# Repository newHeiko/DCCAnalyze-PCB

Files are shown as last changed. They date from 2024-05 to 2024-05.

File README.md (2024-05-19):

# DCCAnalyze hardware

This repo contains the PCB files for a stand-alone DCC analyzer.

## DCCAnalyze firmware

The firmware can be found at [newHeiko/DCCInspector-EX](https://github.com/newHeiko/DCCInspector-EX) which is an extension of [DCC-EX/DCCInspector-EX](https://github.com/DCC-EX/DCCInspector-EX) by the following points (some tbd).

- [x] Add support for Arduino Nano Every
- [ ] Add support for keys
- [ ] Add support for LCD

## Building DCCAnalyze hardware

The PCB was created with kicad 8.0, the production files with the Fabrication Toolkit.

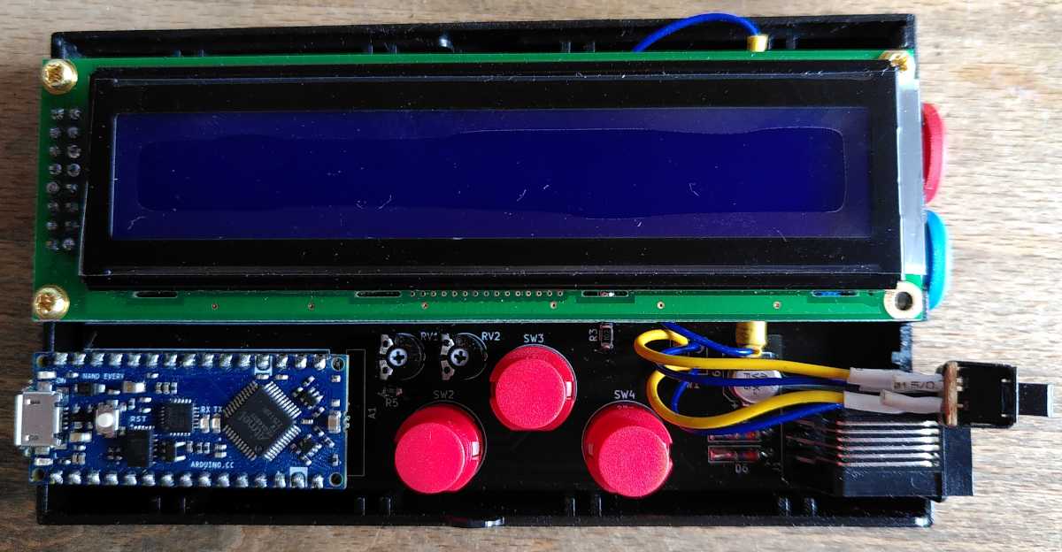
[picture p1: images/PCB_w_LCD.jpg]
View of my first prototype


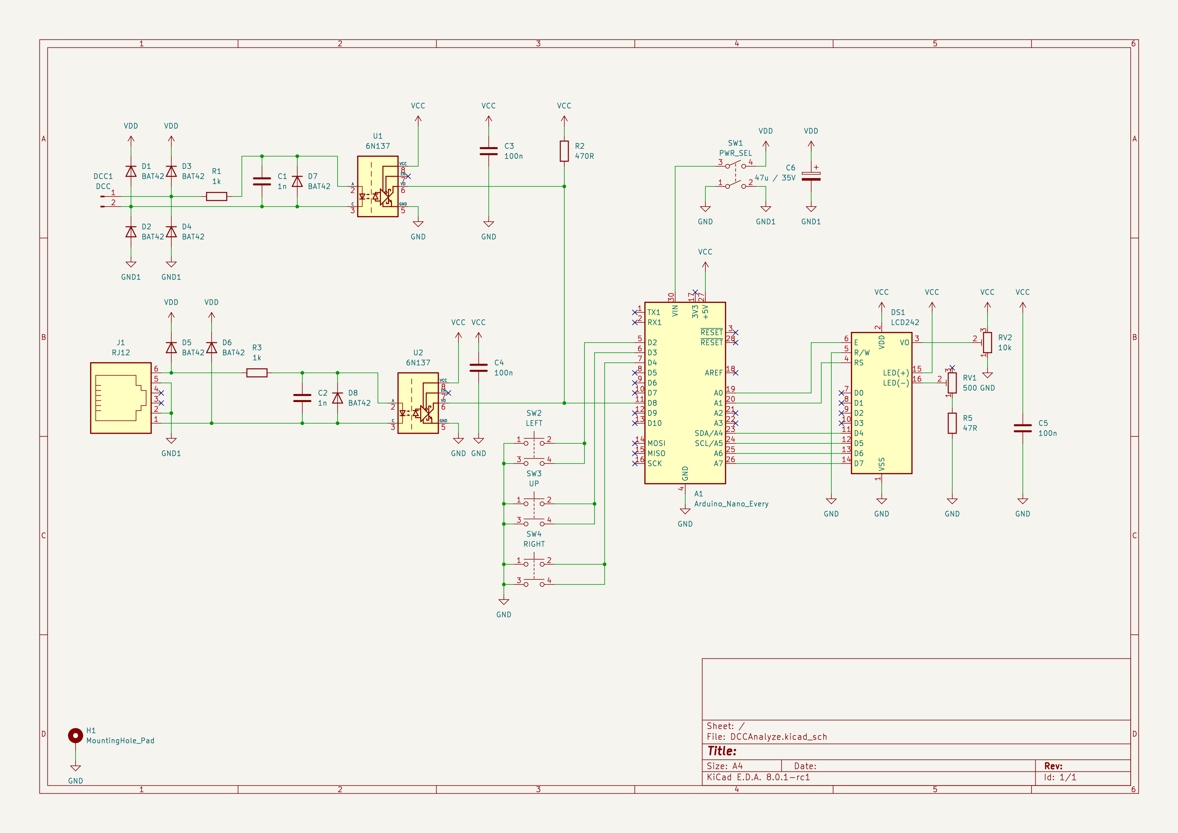
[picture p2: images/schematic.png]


Most of the parts are from my box of spare and leftover parts, which is why I mixed different size SMD parts, some also rather unusual.

This is the full partlist:
| Parts | Value | Notes / Source |
| ----- | ----- | --- |
| A1 | Arduino Nano Every | [Reichelt](https://www.reichelt.de/arduino-nano-every-atmega4809-ohne-header-ard-nano-eve-p261300.html?&nbc=1) |
| C1, C2 | 1nF  | 0805  |
| C3, C4, C5 | 100nF | 1206 |
| C6 | 47µF  | Dia 6.3mm, min 25V |
| D1, D2, D3, D4, D5, D6, D7, D8 | BAT42 | MiniMELF |
| J1 | RJ12-connector | [Reichelt](https://www.reichelt.de/modular-einbaubuchse-6-6-schwarz-mebp-6-6s-p11370.html?&nbc=1) |
| R1, R3 | 1kOhm | 1206 |
| R2 | 470Ohm | 1206 |
| R5 | 47Ohm | 0805 |
| RV1 | 500 Ohm | Piher PT-6 [Reichelt](https://www.reichelt.de/einstellpotentiometer-liegend-500-ohm-6-mm-pt-6-l-500-p14989.html?&nbc=1) |
| RV2 | 10kOhm | Piher PT-6 [Reichelt](https://www.reichelt.de/einstellpotentiometer-liegend-10-kohm-6-mm-pt-6-l-10k-p14982.html?&nbc=1) |
| SW2, SW3, SW4 | Digitast DT6 | [Reichelt](https://www.reichelt.de/eingabetaster-schaltspannung-100v-rund-sw-dt-6-sw-p7241.html?&nbc=1) |
| U1, U2 | 6N137 | DIP8 |
| LCD | 24x2 | [Reichelt](https://www.reichelt.de/lcd-modul-2x24-h-5-6mm-bl-ws-m-bel--lcd-242a-bl-p53951.html?&nbc=1) |
| SW1 | DPST or DPDT | [Reichelt](https://www.reichelt.de/schiebeschalter-miniatur-loetanschluss-2x-um-sw-t-217-p19976.html?&nbc=1) |
| DCC | 2x SKS SEB 2610 F4,8 | 2x [Reichelt](https://www.reichelt.de/einbaubuchse-4-mm-faston-gelb-gesichert-seb-2610f-ge-p106132.html?&nbc=1) |
| PinHeader for A1 | 2x 1x16 | 2x [Reichelt](https://www.reichelt.de/stiftleisten-2-54-mm-1x16-gerade-mpe-087-1-016-p119887.html?&nbc=1) |
| Socket for A1 | 2x 1x16 | 2x [Reichelt](https://www.reichelt.de/buchsenleisten-2-54-mm-1x16-gerade-mpe-094-1-016-p119919.html?&nbc=1) |
| PinHeader for LCD | 2x8 | [Reichelt](https://www.reichelt.de/stiftleisten-2-54-mm-2x08-gerade-mpe-087-2-016-p119897.html?&nbc=1) |
| Socket for LCD | 2x8 | [Reichelt](https://www.reichelt.de/buchsenleiste-2x8-pol-vergoldet-2-54-bkl-10120808-p235674.html?&nbc=1) |
| 3x LCD stand-offs | 3x M2.5 x 12mm | |
| LCD screws | 6x M2.5 x 6mm | |
| PCB screw | 1x Dia 2.9mm x 6.5mm | |
| Enclosure | | 2x [Reichelt](https://www.reichelt.de/kunststoff-halbschale-123-x-70-x-14-5-mm-sd-10-gr-halb-p149274.html?&nbc=1) |

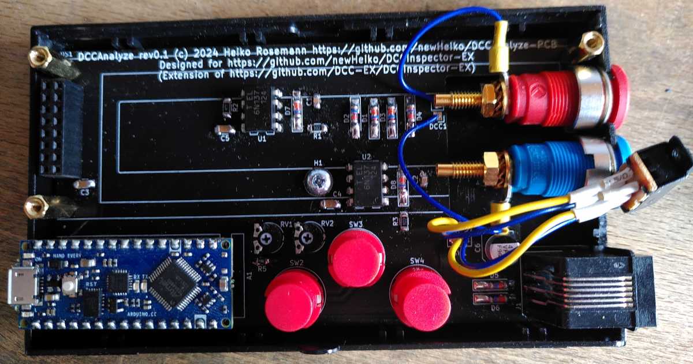
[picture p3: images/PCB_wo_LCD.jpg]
PCB inside the lower half of the housing, with the LCD removed


The device can decode the DCC signal either from the loconet(r) plug and its Railsync signal or from the two 4mm sockets. The sockets included in the BOM above are shorter than the ones I used for my prototype - they should fit in the recess of the PCB.

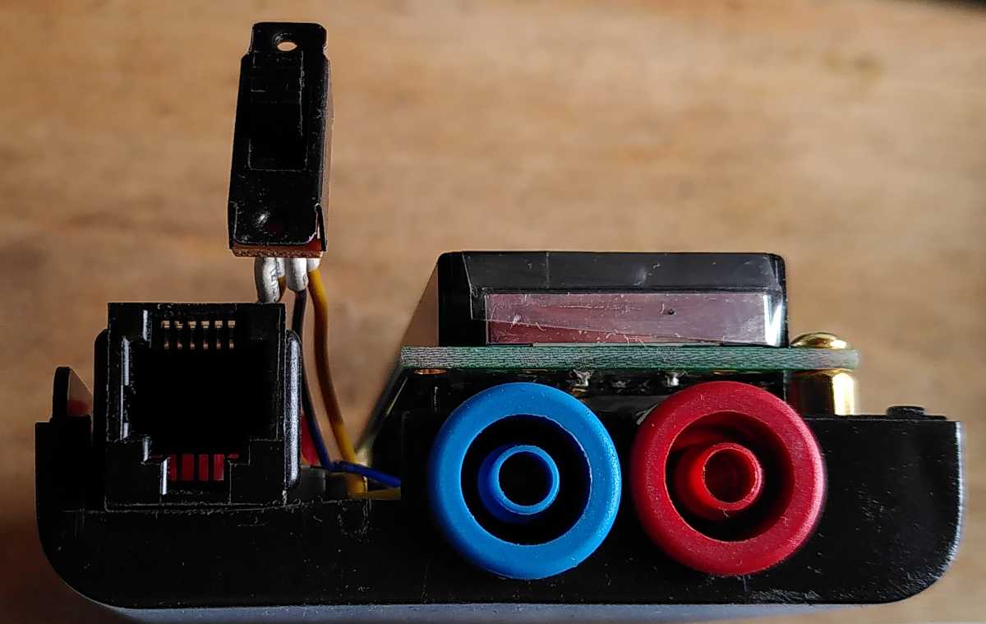
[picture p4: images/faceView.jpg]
Side view of the device


Power can come from the USB connection (then the DCC inputs both are optically isolated from everything else) or from the DCC / Railsync signal (then the USB connection is not required and the device can be used stand-alone). Power draw from DCC / Railsync is about 25mA-30mA at 15V.

The switch SW1 switches the device power from USB to DCC/Railsync. It should fit vertically between the RJ12 socket and the LCD / 4mm plugs.

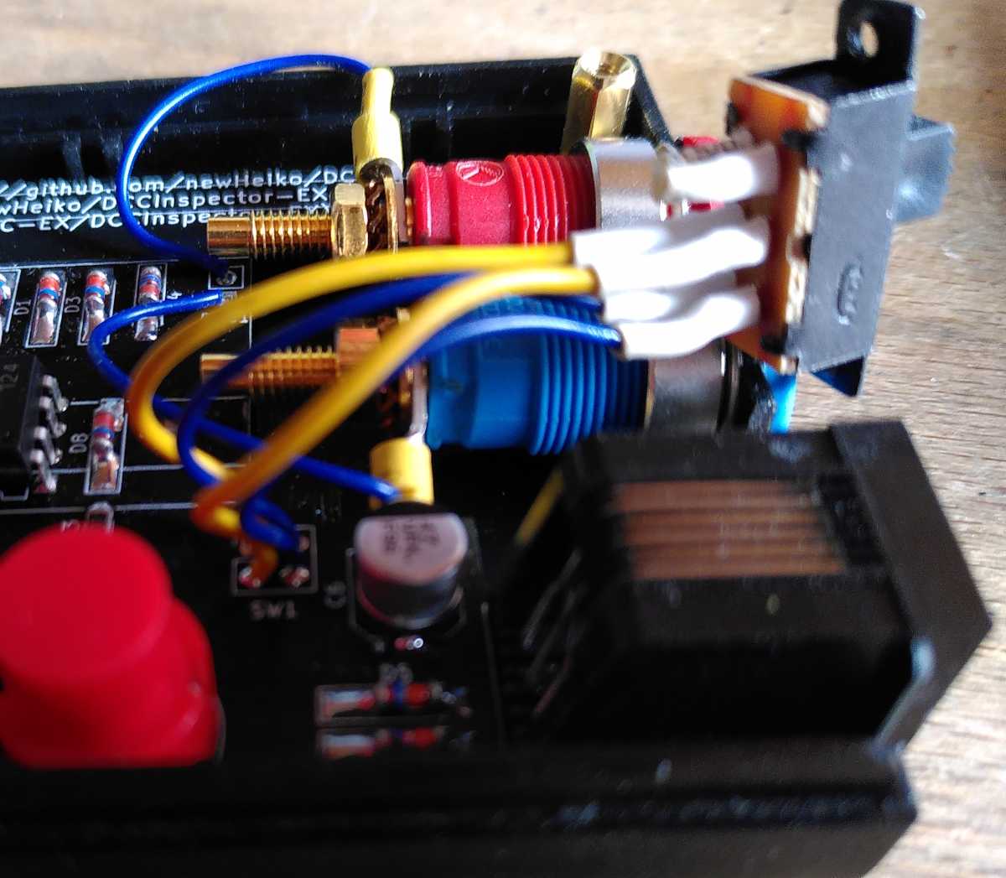
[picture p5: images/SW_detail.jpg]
Detail view of power switch connection


Note that for the switch, the polarity matters. In the image above, the lower yellow wire needs to connect to the lower blue wire and the upper yellow wire to the upper blue wire.

You may substitute a classic Arduino Nano for the Arduino Nano Every, but the integrated linear voltage regulator of the classic Arduino Nano will probably get very hot. Beware of DCC / Railsync input voltages above ~12V or so in that case.

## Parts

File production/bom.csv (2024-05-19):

Designator | Footprint | Quantity | Value | LCSC Part #
A1 | Arduino_Nano | 1 | Arduino_Nano_Every
C1, C2 | 0805 | 2 | 1n
C3, C4, C5 | 1206 | 3 | 100n
C6 | CP_Elec_6.3x5.8 | 1 | 47u / 35V
D1, D2, D3, D4, D5, D6, D7, D8 | D_MiniMELF_Handsoldering | 8 | BAT42
DCC1 | PinHeader_1x02_P2.54mm_Vertical | 1 | DCC
DS1 | LCD242 | 1 | LCD242
J1 | RJ12_Amphenol_54601-x06_Horizontal | 1 | RJ12
R1, R3 | 1206 | 2 | 1k
R2 | 1206 | 1 | 470R
R5 | 0805 | 1 | 47R
RV1 | Potentiometer_Piher_PT-6-V_Vertical | 1 | 500
RV2 | Potentiometer_Piher_PT-6-V_Vertical | 1 | 10k
SW1 | PinHeader_2x02_P2.54mm_Vertical | 1 | PWR_SEL
SW2 | Push_E-Switch_KS01Q01 | 1 | LEFT
SW3 | Push_E-Switch_KS01Q01 | 1 | UP
SW4 | Push_E-Switch_KS01Q01 | 1 | RIGHT
U1, U2 | DIP-8_W7.62mm | 2 | 6N137

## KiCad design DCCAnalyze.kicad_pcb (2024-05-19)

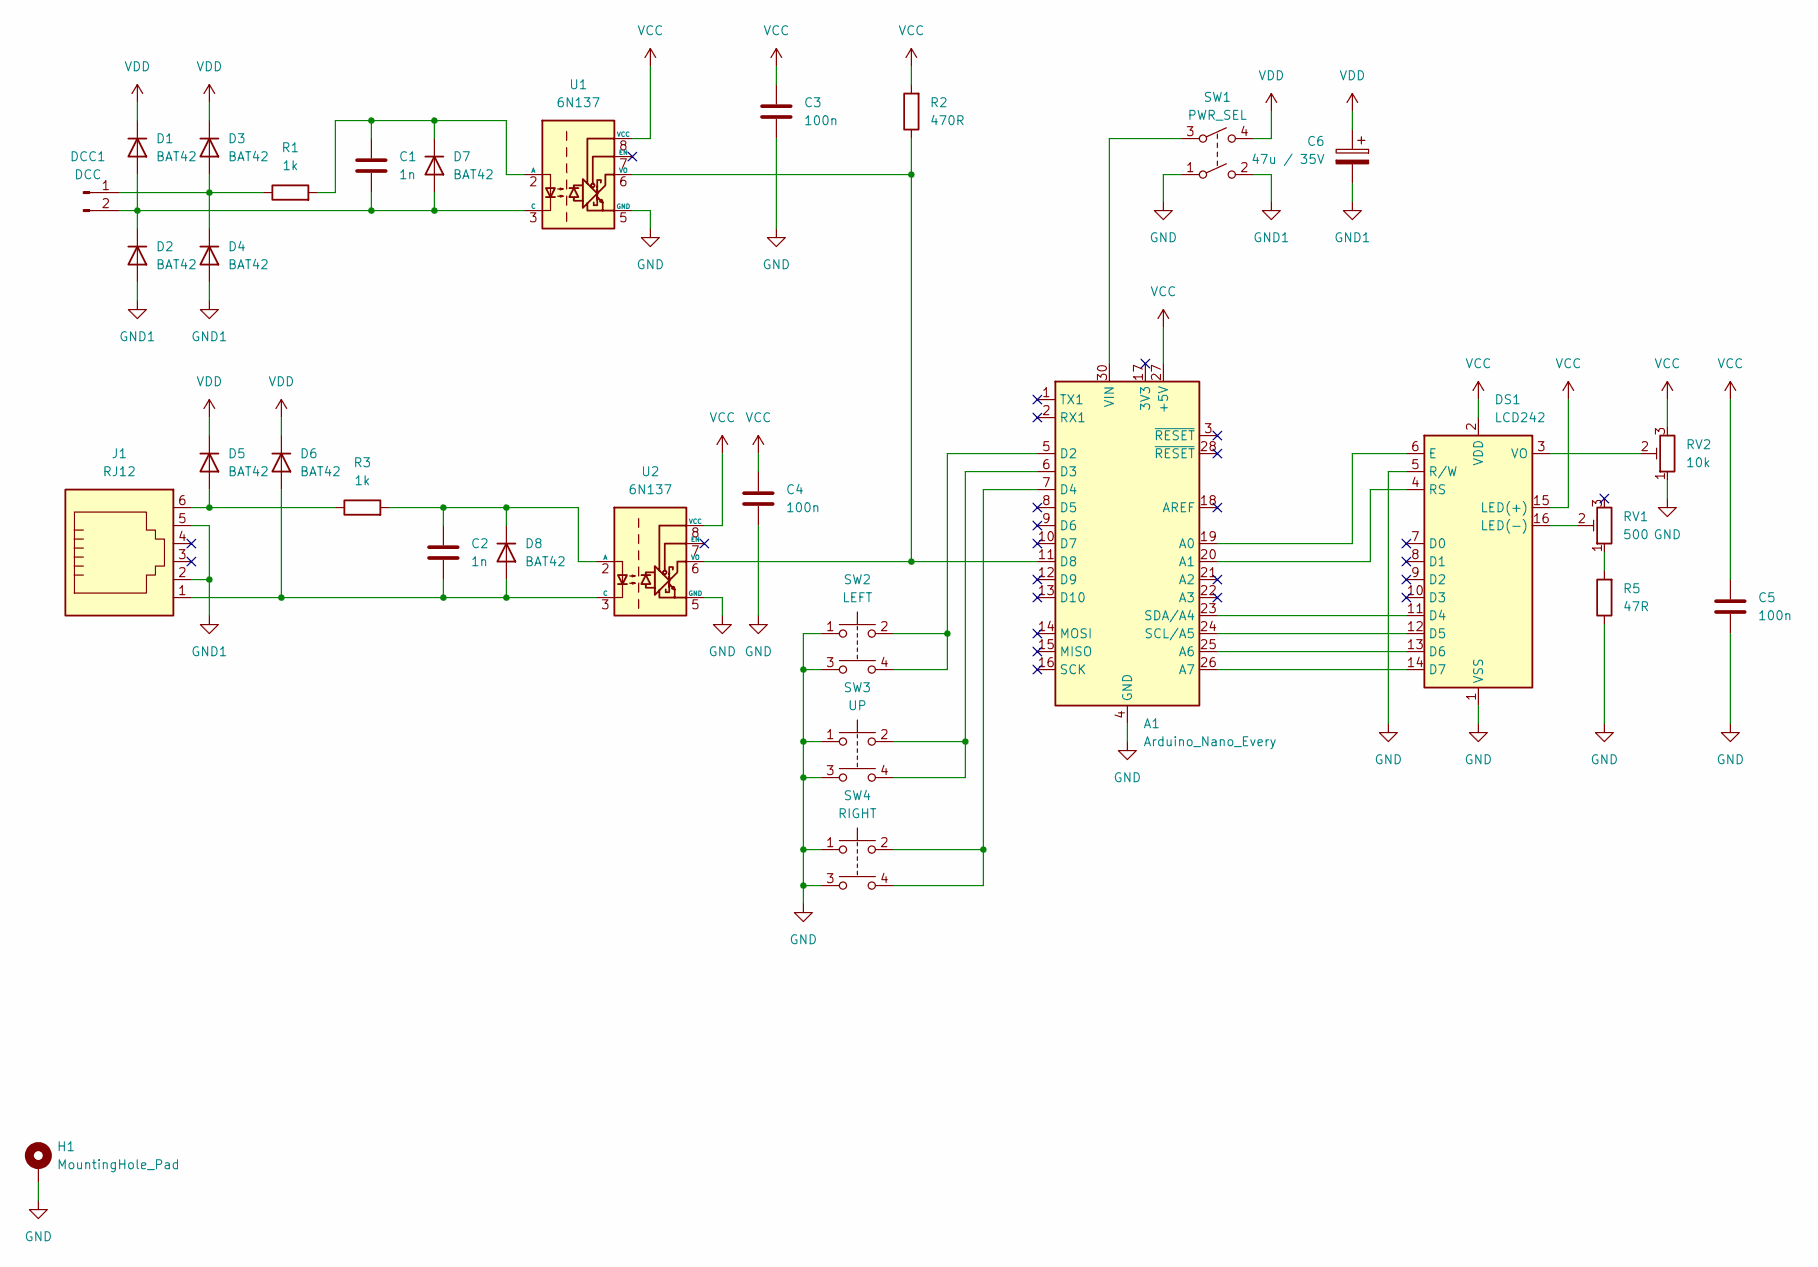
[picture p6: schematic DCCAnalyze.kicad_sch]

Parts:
A1: Arduino_Nano_Every; Arduino_Nano
C1, C2: 1n; C_0805_2012Metric_Pad1.18x1.45mm_HandSolder
C3, C4, C5: 100n; C_1206_3216Metric_Pad1.33x1.80mm_HandSolder
C6: 47u / 35V; CP_Elec_6.3x5.8
D1, D2, D3, D4, D5, D6, D7, D8: BAT42; D_MiniMELF_Handsoldering
DCC1: DCC; PinHeader_1x02_P2.54mm_Vertical
DS1: LCD242
H1: MountingHole_Pad; MountingHole_3.2mm_M3_Pad
J1: RJ12; RJ12_Amphenol_54601-x06_Horizontal
R1, R3: 1k; R_1206_3216Metric_Pad1.30x1.75mm_HandSolder
R2: 470R; R_1206_3216Metric_Pad1.30x1.75mm_HandSolder
R5: 47R; R_0805_2012Metric_Pad1.20x1.40mm_HandSolder
RV1: 500; Potentiometer_Piher_PT-6-V_Vertical
RV2: 10k; Potentiometer_Piher_PT-6-V_Vertical
SW1: PWR_SEL; PinHeader_2x02_P2.54mm_Vertical
SW2: LEFT; Push_E-Switch_KS01Q01
SW3: UP; Push_E-Switch_KS01Q01
SW4: RIGHT; Push_E-Switch_KS01Q01
U1, U2: 6N137; DIP-8_W7.62mm

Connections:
GND: A1.4 (GND), A1.29 (GND), C3.2, C4.2, C5.2, DS1.1 (VSS), DS1.5 (R/W), H1.1, R5.1, RV2.1, SW1.1, SW2.1, SW2.3, SW3.1, SW3.3, SW4.1, SW4.3, U1.5 (GND), U2.5 (GND)
GND1: C6.2, D2.2 (A), D4.2 (A), J1.2, J1.5, SW1.2
unnamed: A1.19 (A0), DS1.6 (E)
unnamed: A1.20 (A1), DS1.4 (RS)
unnamed: A1.25 (A6), DS1.13 (D6)
unnamed: A1.26 (A7), DS1.14 (D7)
unnamed: A1.5 (D2), SW2.2, SW2.4
unnamed: A1.6 (D3), SW3.2, SW3.4
unnamed: A1.7 (D4), SW4.2, SW4.4
unnamed: A1.11 (D8), R2.1, U1.6 (VO), U2.6 (VO)
unnamed: A1.24 (SCL/A5), DS1.12 (D5)
unnamed: A1.23 (SDA/A4), DS1.11 (D4)
unnamed: A1.30 (VIN), SW1.3
unnamed: C1.2, D1.2 (A), D2.1 (K), D7.2 (A), DCC1.2, U1.3 (C)
unnamed: D3.2 (A), D4.1 (K), DCC1.1, R1.1
unnamed: D5.2 (A), J1.6, R3.1
unnamed: C2.2, D6.2 (A), D8.2 (A), J1.1, U2.3 (C)
unnamed: C1.1, D7.1 (K), R1.2, U1.2 (A)
unnamed: C2.1, D8.1 (K), R3.2, U2.2 (A)
unnamed: DS1.16 (LED(-)), RV1.2
unnamed: DS1.3 (VO), RV2.2
unnamed: R5.2, RV1.1
VCC: A1.27 (+5V), C3.1, C4.1, C5.1, DS1.2 (VDD), DS1.15 (LED(+)), R2.2, RV2.3, U1.8 (VCC), U2.8 (VCC)
VDD: C6.1, D1.1 (K), D3.1 (K), D5.1 (K), D6.1 (K), SW1.4

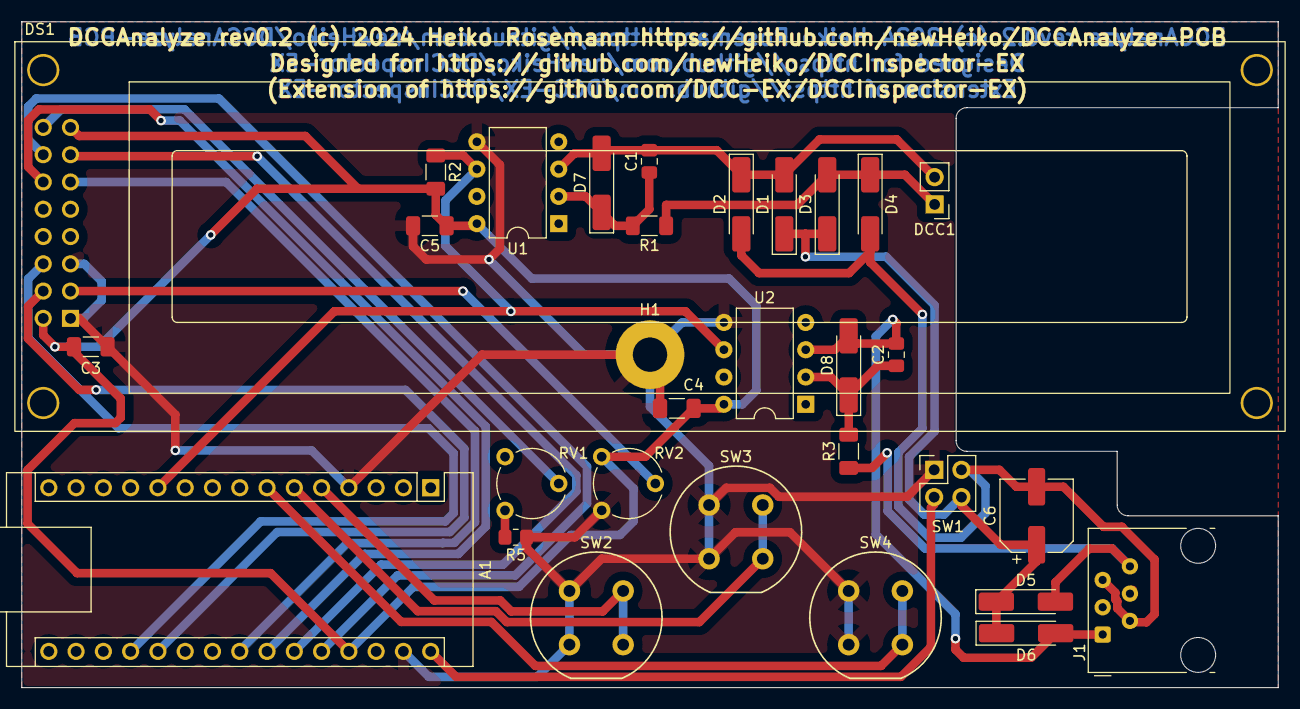
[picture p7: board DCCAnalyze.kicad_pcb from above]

Board: 2 copper layers, 117.0 x 62.0 mm, 31 parts (0 on the bottom side), 24 nets.

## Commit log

2024-05-17 Add PCB v0.1 to github.
    [DCCAnalyze.kicad_pcb, DCCAnalyze.kicad_sch, bom.csv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]
2024-05-17 Add gitignore for kicad backups
2024-05-17 Add some kicad interface file
2024-05-18 Move RJ12 connector inwards to match housing.
    ...for rev0.2
    [DCCAnalyze.kicad_pcb]
2024-05-19 Add position of power switch.
2024-05-19 Correct LCD value
    [DCCAnalyze.kicad_pcb, DCCAnalyze.kicad_sch]
2024-05-19 Update production data
    [bom.csv, positions.csv]
2024-05-19 Add schematic images
2024-05-19 Add power consumption information.

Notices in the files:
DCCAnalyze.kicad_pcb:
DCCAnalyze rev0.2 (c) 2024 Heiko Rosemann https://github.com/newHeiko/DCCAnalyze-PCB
